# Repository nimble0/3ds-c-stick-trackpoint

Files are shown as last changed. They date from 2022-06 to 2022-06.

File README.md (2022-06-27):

# 3DS C-stick as a trackpoint

This is not complicated to do but I didn't find any guides on this or even anyone saying they'd done it, so I made this little guide.

3DS C-stick as a trackpoint in action

## Circuitry

This is the C-stick module:

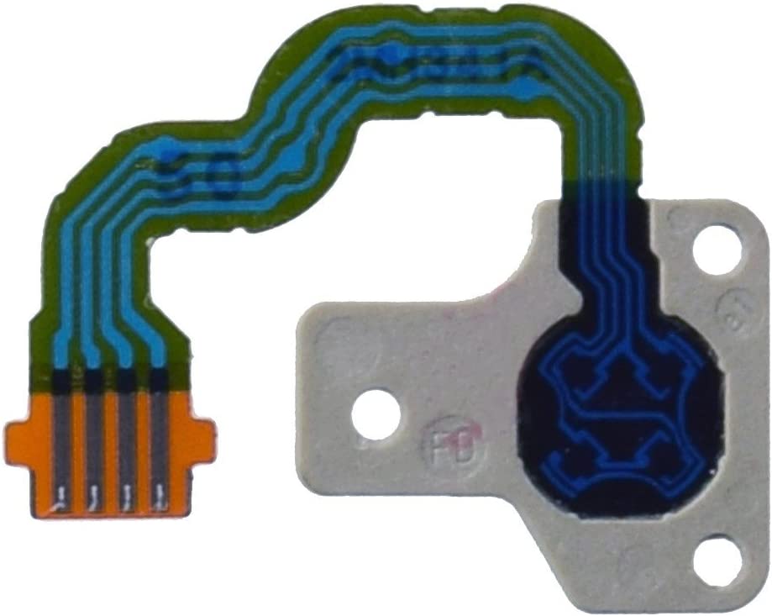
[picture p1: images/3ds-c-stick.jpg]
3DS C-stick


The C-stick module has 4 pressure sensistive variable resistors:

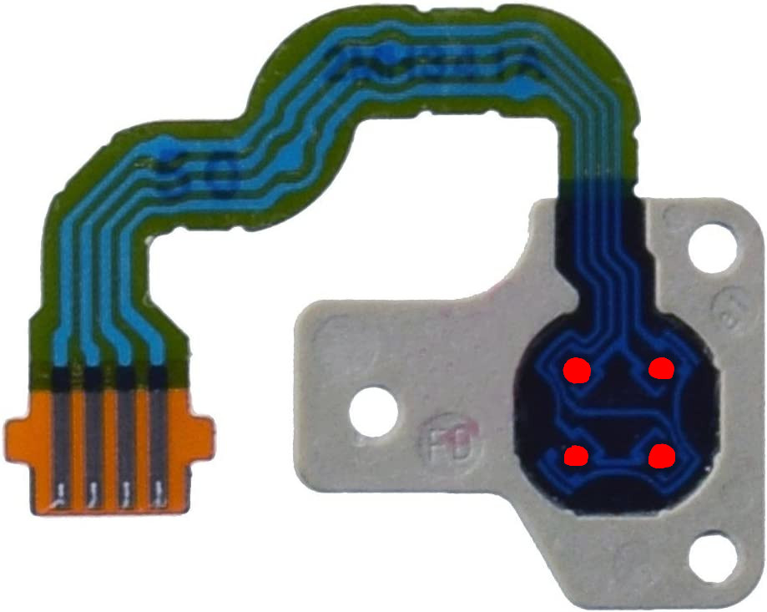
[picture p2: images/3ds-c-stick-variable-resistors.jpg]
3DS C-stick variable resistors


These are the two circuits (one for each axis) we'll use with the C-stick module:

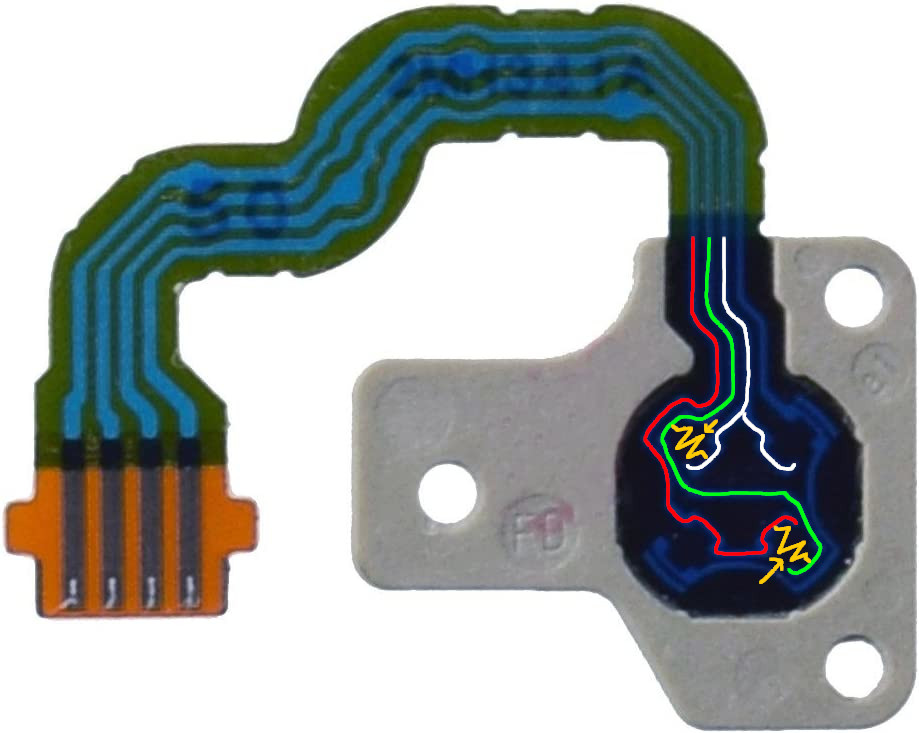
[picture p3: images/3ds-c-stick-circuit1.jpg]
3DS C-stick circuit 1

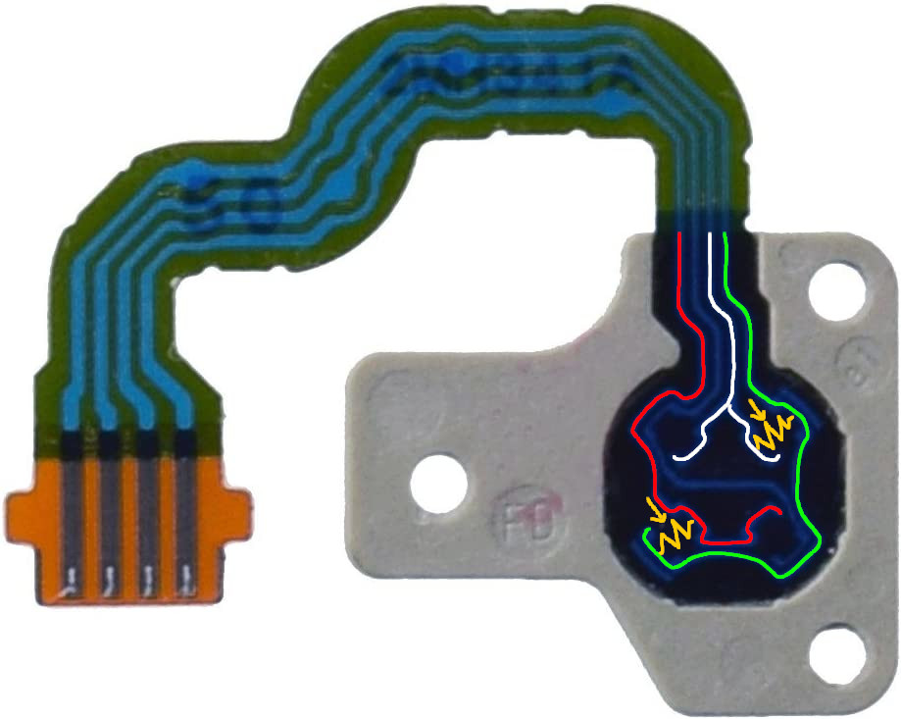
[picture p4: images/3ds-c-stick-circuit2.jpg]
3DS C-stick circuit 2


- Red is connected to VCC.
- White is connected to ground.
- Green is between 2 of the variable resistors and where we read the voltage.

## Connecting wires

In order to connect wires to the C-stick module you'll need a 4-pin FFC (FPC) ZIF connector with 1mm pitch. These are usually surface mount, so a PCB is preferred. However if you don't want to use a PCB, this is what I did:

3D print this:

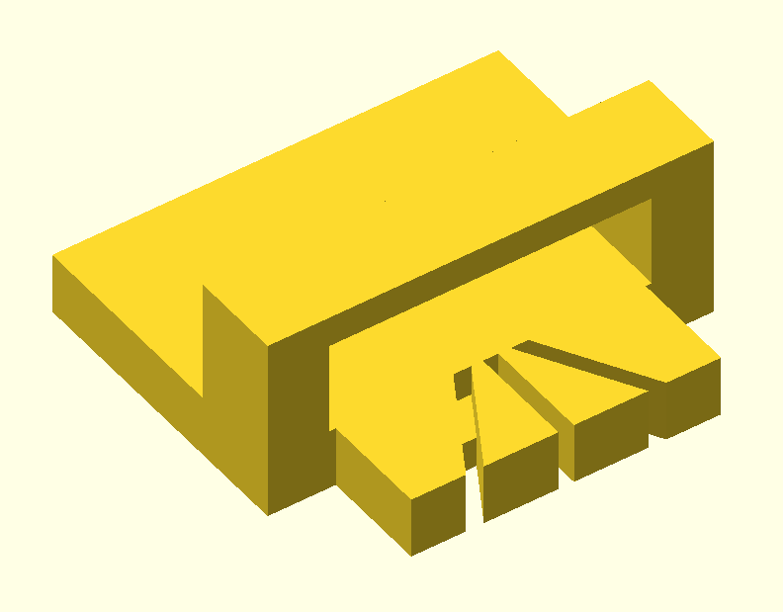
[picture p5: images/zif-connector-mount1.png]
3D-printed ZIF connector mount for hand wiring

- [OpenSCAD file](./parts/zif-connector-mount.scad)
- [STL file](./parts/zif-connector-mount.stl)

Put copper tape around here:

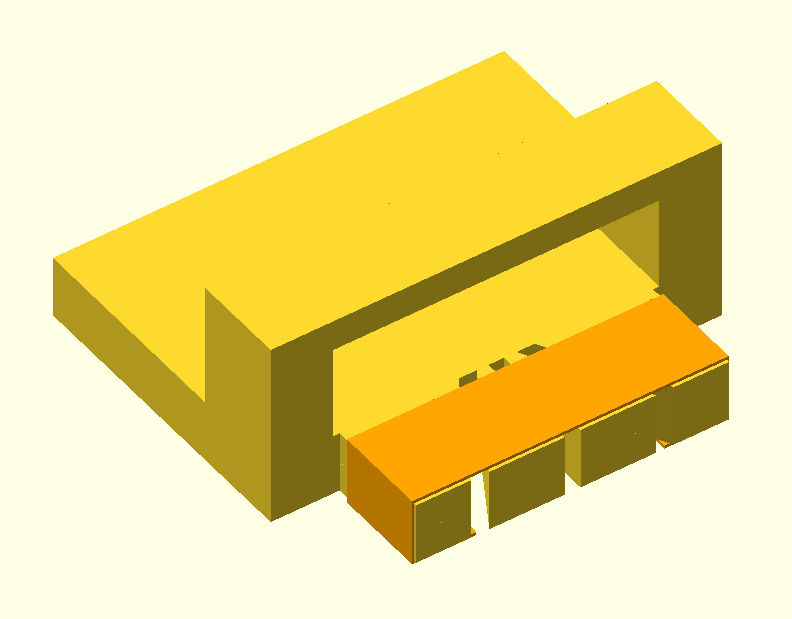
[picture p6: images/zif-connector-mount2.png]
3D-printed ZIF connector mount for hand wiring with copper tape


Cut the tape at the grooves:

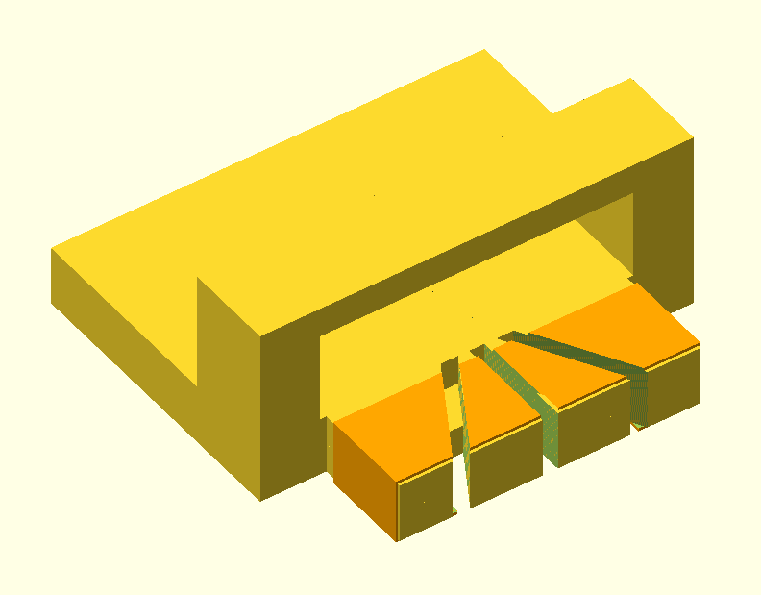
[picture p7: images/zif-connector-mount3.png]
3D-printed ZIF connector mount for hand wiring with copper tape cut into 4 pads


Bend the connector pins into a fan so they line up with the 4 areas of on the copper tape. Now you have some larger pads you can solder both the pins and wires to.

Final result:

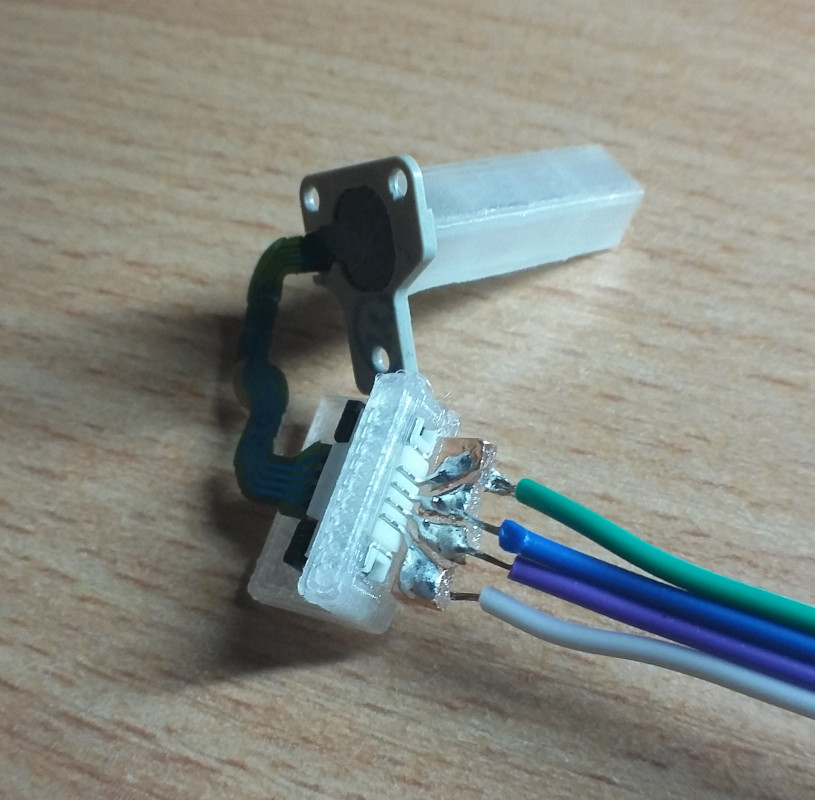
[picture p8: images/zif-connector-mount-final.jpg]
3D-printed ZIF connector mount for hand wiring soldered to wires


## Signal strength

Signal strength is weak with the stock nub and a 10bit ADC. A 20mm 3D-printed nub helps. Using a 12bit ADC for a 4x increase in resolution should be a good boost.

## Firmware

[Basic firmware for Arduino](./firmware/arduino.cpp) (Bad deadzone implementation; prevents small movements.)

## Buying

3DS C-stick modules are available on AliExpress/Alibaba. Single unit is around 15 USD. When buying in bulk (20+ units) the price goes down to around 5 USD.

The ZIF connectors can be found on many electonics stores (eg/ Mouser) or eBay. These typically cost under 1 USD each but you may have to buy a multiple.

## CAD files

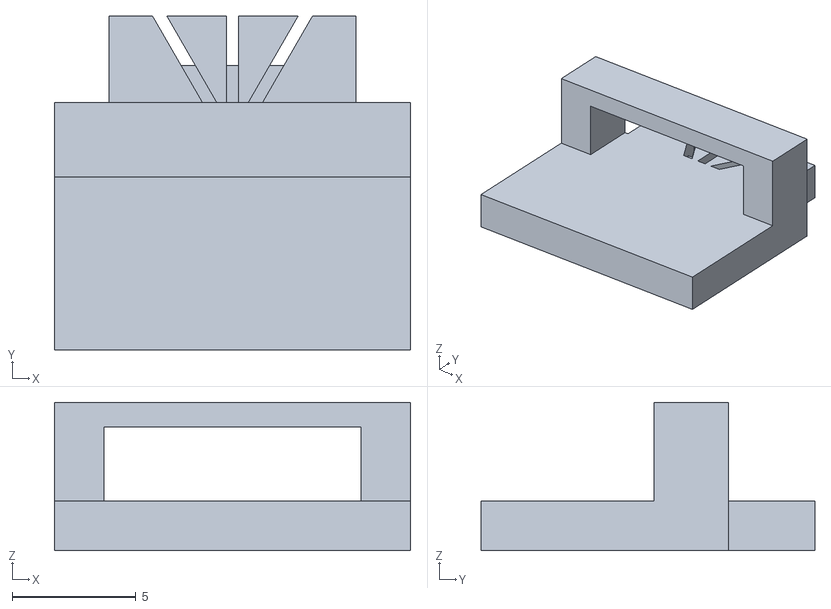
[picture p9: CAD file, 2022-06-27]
parts/zif_connector_mount.stl
14.4 x 13.5 x 6.00

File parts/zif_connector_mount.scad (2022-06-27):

module wiring_channels()
{
	difference()
	{
		square([10, 5], center = true);
		
		square([0.5, 5], center = true);
		translate([1.5, 0])
			rotate(-30)
			square([0.5, 8], center = true);
		translate([-1.5, 0])
			rotate(30)
			square([0.5, 8], center = true);
	}
}

linear_extrude(2)
{
	translate([0, -10 + 4]) square([14 + 0.4, 10], center = true);

	wiring_channels();
}

linear_extrude(1)
{
	translate([0, -10 + 5.5]) square([10, 10], center = true);

	wiring_channels();
}

linear_extrude(2.5 + 3)
	translate([10 / 2 + 1.2, -2.5])
	square([2, 3], center = true);
translate([0, 0, 2 + 3])
	linear_extrude(1)
	translate([10 / 2 + 0.7, -2.5])
	square([3, 3], center = true);

linear_extrude(2.5 + 3)
	translate([-(10 / 2 + 1.2), -2.5])
	square([2, 3], center = true);
translate([0, 0, 2 + 3])
	linear_extrude(1)
	translate([-(10 / 2 + 0.7), -2.5])
	square([3, 3], center = true);

translate([0, 0, 2 + 3])
	linear_extrude(1)
	translate([0, -2.5])
	square([14 + 0.4, 3], center = true);

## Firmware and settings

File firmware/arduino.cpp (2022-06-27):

#include <Mouse.h>

int deadzone = 2;

int centreX = 0;
int centreY = 0;

void setup()
{
  pinMode(A0, INPUT);
  pinMode(A1, INPUT);
  
  centreX = analogRead(A0);
  centreY = analogRead(A1);

  Serial.begin(9600); //This pipes to the serial monitor
  Serial.println("Initialize Serial Monitor");

  Serial1.begin(9600); //This is the UART, pipes to sensors attached to board
  Serial1.println("Initialize Serial Hardware UART Pins");
}

void loop()
{
  int x = analogRead(A0) - centreX;
  int y = analogRead(A1) - centreY;

  Serial.print("move ");
  Serial.print(x);
  Serial.print(", ");
  Serial.print(y);
  Serial.println();

  if(abs(x) >= deadzone || abs(y) >= deadzone) 
    Mouse.move(x, y, 0);
  
  delay(8);
}
